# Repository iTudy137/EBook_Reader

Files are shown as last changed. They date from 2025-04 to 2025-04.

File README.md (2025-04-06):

### Copyright Dinca Tudor-Cristian 332CA 2025

# OpenBook E-Reader

1. [Block Diagram](#block-diagram)
2. [Bill of Materials](#bill-of-materials)
3. [Hardware Details](#hardware-functionality)
4. [ESP32-C6 Pins](#ESP32-C6-pin-mapping)

# Block Diagram

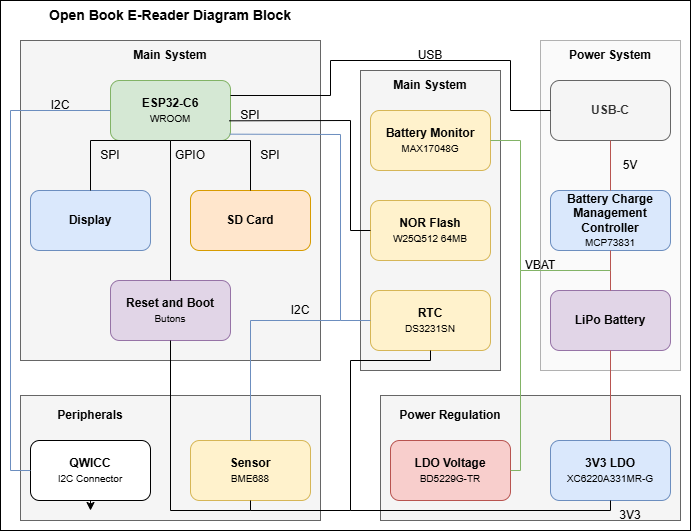
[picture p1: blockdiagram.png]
OpenBook Block Diagram


---

# Bill of Materials

| Qty | Description | Value | Parts | AVAILABILITY | CHECK_PRICES | DATASHEET |
| --- | --- | --- | --- | --- | --- | --- |
| 1 | LED | | CHG_LED | In Stock | https://ro.mouser.com/ProductDetail/ams-OSRAM/LB-Q99G.01-P1R1-35-1?qs=IPgv5n7u5QZHWhEkNg3xgA%3D%3D | https://ro.mouser.com/datasheet/2/588/prd_pim_datasheet_23471863_EN_pdf-3317093.pdf |
| 1 | SMD solder JUMPER | | SJ1 | In Stock | https://ro.mouser.com/ProductDetail/Vishay-Dale/CRCW04020000Z0EEHP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 | https://www.vishay.com/docs/20043/crcwhpe3.pdf |
| 1 | CAPACITOR, European symbol | 0.1uF/50V | EPD_C5 | In Stock | [https://ro.mouser.com/ProductDetail/Walsin/0402N151F500CT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](https://ro.mouser.com/ProductDetail/Walsin/0402N151F500CT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) | [https://ro.mouser.com/datasheet/2/210/WTC_MLCC_General_Purpose-1534899.pdf](https://ro.mouser.com/datasheet/2/210/WTC_MLCC_General_Purpose-1534899.pdf) |
| 1 | RESISTOR, European symbol | 0.47 | R3 | In Stock | https://ro.mouser.com/ProductDetail/Panasonic/ERJ-2BQJR47X?qs=18kBAoNi3c8r%252BkU3FsPM2Q%3D%3D | https://industrial.panasonic.com/cdbs/www-data/pdf/RDN0000/AOA0000C313.pdf |
| 1 | RESISTOR, European symbol | 100K | R1_PWRUSB | In Stock | [https://ro.mouser.com/ProductDetail/Welwyn-Components-TT-Electronics/WCR0402-100KFA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](https://ro.mouser.com/ProductDetail/Welwyn-Components-TT-Electronics/WCR0402-100KFA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) | https://ro.mouser.com/datasheet/2/414/TTRB_S_A0012915158_1-2565570.pdf |
| 6 | CAPACITOR, European symbol | 100nF | C1, C2, C6, C8, C10, C_DELAY | In Stock | https://ro.mouser.com/ProductDetail/KYOCERA-AVX/04023C104KAT2A-62?qs=%252BdQmOuGyFcH%2FNuvX5KIF9Q%3D%3D | https://ro.mouser.com/datasheet/2/40/X7RDielectric-2943470.pdf |
| 2 | CAPACITOR, European symbol | 100nF | C4_USB, C9 | In Stock | https://ro.mouser.com/ProductDetail/KYOCERA-AVX/04023C104KAT2A-62?qs=%252BdQmOuGyFcH%2FNuvX5KIF9Q%3D%3D | https://ro.mouser.com/datasheet/2/40/X7RDielectric-2943470.pdf |
| 1 | POLARIZED CAPACITOR, European symbol | 100uF TANT | C3 | In Stock | https://ro.mouser.com/ProductDetail/KYOCERA-AVX/TCJB106M020R0150E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 | https://ro.mouser.com/datasheet/2/40/TCJ-2887130.pdf |
| 16  | RESISTOR, European symbol | 10K | R1, R1_PINH, R1_PINH1, R2-PINH, R2-PINH1, R4, R5, R6, R7, R8, R9, R10, R_BOOT, R_CHANGE, R_CL1, R_RESET | In Stock | https://ro.mouser.com/ProductDetail/YAGEO/RC0402FR-07100KL?qs=mnq%2FyloZIXzTlUn7JAHSWg%3D%3D | https://ro.mouser.com/datasheet/2/447/YAGEO_PYu_RC_Group_51_RoHS_L_12-3313492.pdf |
| 1 | CAPACITOR, European symbol | 10uF | C7 | In Stock | https://ro.mouser.com/ProductDetail/KYOCERA-AVX/KAM05AR71E103KH?qs=Jm2GQyTW%2FbgMbf7pmhTrvw%3D%3D | https://ro.mouser.com/datasheet/2/40/AutoMLCCKAM-3216307.pdf |
| 1 | Micro SD Card Socket, Push-Push Type, Top Mount, SMT, H=1.83mm, 10u | 112A-TAAR-R03_ATTEND | J4 | In Stock | https://www.soselectronic.com/ro-ro/products/attend/112a-taar-r03-116052 | https://cdn.soselectronic.com/productdata/bd/ac/42954337/112a-taar-r03.pdf |
| 1 | RESISTOR, European symbol | 15 | R_CAPACITOR | In Stock | https://ro.mouser.com/ProductDetail/Bourns/CR0402-FX-15R0GLF?qs=sGAEpiMZZMtlubZbdhIBICGkyIRIR3aIuucn1Gj71Hk%3D | https://ro.mouser.com/datasheet/2/54/cr-1858361.pdf |
| 1 | CAPACITOR, European symbol | 1uF | C5 | In Stock | https://ro.mouser.com/ProductDetail/TAIYO-YUDEN/MAASL105CC7105MFCA01?qs=HFfMDpzxxd1Fn%2FInbJA7vw%3D%3D | https://ro.mouser.com/datasheet/2/396/TAIYO_YUDEN_04_27_2024_c_mlcc_A_e1-3451516.pdf |
| 9 | CAPACITOR, European symbol | 1uF/50V | EPD_C1, EPD_C2, EPD_C6, EPD_C7, EPD_C8, EPD_C9, EPD_C10, EPD_C11, EPD_C12 | In Stock | https://ro.mouser.com/ProductDetail/TAIYO-YUDEN/MAASU32NSB7105KTCA01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 | https://ro.mouser.com/datasheet/2/396/TDK_4_24_2024_MAASU32NSB7105KTCA01_SS-3440852.pdf |
| 1 | RESISTOR, European symbol | 2.2 | R2 | In Stock | https://ro.mouser.com/ProductDetail/YAGEO/RC0402JR-072R2L?qs=sGAEpiMZZMtlubZbdhIBIDHZZHtX2mqkbiSU5pja5tk%3D | https://ro.mouser.com/datasheet/2/447/YAGEO_PYu_RC_Group_51_RoHS_L_12-3313492.pdf |
| 1 | RESISTOR, European symbol | 200 | R1_BAT | In Stock | https://ro.mouser.com/ProductDetail/Panasonic/ERJ-U02D2000X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 | https://industrial.panasonic.com/cdbs/www-data/pdf/RDP0000/AOA0000C334.pdf |
| 2 | P-channel MOSFETs | 20V/4.2A/52mO/1.4W | Q1, Q2 | In Stock | https://ro.mouser.com/ProductDetail/Diodes-Incorporated/DMG2305UX-7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 | https://www.diodes.com/assets/Datasheets/DMG2305UX.pdf |
| 1 | RESISTOR, European symbol | 2K | R2_BAT | In Stock | https://ro.mouser.com/ProductDetail/Vishay-Dale/CRCW04022K00JNTD?qs=D1%252BtGGlbRE%252BwoJgrHBlX1g%3D%3D | https://www.vishay.com/docs/20008/dcrcw.pdf |
| 2 | CAPACITOR, European symbol | 4.7uF | C1_BAT, C2_BAT | In Stock | https://ro.mouser.com/ProductDetail/KEMET/C0402C475K8PACTU?qs=ulEaXIWI0c9ebKRT3r3htg%3D%3D | https://ro.mouser.com/datasheet/2/447/KEM_C1006_X5R_SMD-3316465.pdf |
| 3 | CAPACITOR, European symbol | 4.7uF | C1_BAT1, C1_BAT2, C5_USB | In Stock | https://ro.mouser.com/ProductDetail/KEMET/C0402C475K8PACTU?qs=ulEaXIWI0c9ebKRT3r3htg%3D%3D | https://ro.mouser.com/datasheet/2/447/KEM_C1006_X5R_SMD-3316465.pdf |
| 1 | CAPACITOR, European symbol | 4.7uF/25V | C4 | In Stock | https://ro.mouser.com/ProductDetail/KYOCERA-AVX/CM05X5R475M25AH?qs=MyNHzdoqoQJvFdZaEuclBg%3D%3D | https://ro.mouser.com/datasheet/2/40/CM_Series_e-2835982.pdf |
| 2 | RESISTOR, European symbol | 5k1 | R2-USB, R2-USB1 | In Stock | https://ro.mouser.com/ProductDetail/Vishay-Beyschlag/MCS04020C5101FE000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 | https://www.vishay.com/docs/28705/mcx0x0xpro.pdf |
| 1 | | 68uH | L1 | In Stock | https://www.digikey.de/en/products/detail/w%C3%BCrth-elektronik/744043680/1638515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 | https://www.we-online.com/components/products/datasheet/744043680.pdf |
| 1 | Voltage Detector with Adjustable Delay Time: CMOS processes are utilized to develop high precision, low current consumption CMOS reset ICs that allow arbitrary setting of the delay time. The extensive lineup includes both Nch Open Drain and CMOS output types in a wide range of detection voltages (from 2.3V to 6.0V, in 0.1V steps), enabling selection of the ideal solution based on customer requirements. In addition, the entire series is of course both lead-free and RoHS-compliant. | BD5229G-TR | IC1 | In Stock | https://ro.mouser.com/ProductDetail/ROHM-Semiconductor/BD5229G-1TR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 | https://fscdn.rohm.com/en/products/databook/datasheet/ic/power/voltage_detector/bd52xxg-1-e.pdf |
| 3 | | BUTTON_CUSYOMV1 | BOOT_BUTTON, CHANGE_BUTTON, RESET_BUTTON | Restricted Availability | https://ro.mouser.com/ProductDetail/Panasonic/EVQ-P7B01K?qs=Ow%252BOiPmaljGz0yYR%252BWV0ZQ%3D%3D | https://industry.panasonic.com/global/en/downloads/?file_cd=402906&tab=catalog&series_cd=3457 |
| 1 | Cap 0.011F 3.3V 1210 Flat Check availability | CPH3225A | C10_SUPERCAP | Not in stock | [https://www.snapeda.com/parts/CPH3225A/Seiko+Instruments/view-part/?ref=eda](https://www.snapeda.com/parts/CPH3225A/Seiko+Instruments/view-part/?ref=eda) | https://www.snapeda.com/parts/CPH3225A/Seiko%20Instruments/datasheet/ |
| 1 | Real Time Clock Serial 16-Pin SOIC W T/R     Check availability | DS3231SN# | U3 | In Stock | [https://www.snapeda.com/parts/DS3231SN%23/Analog+Devices/view-part/?ref=eda](https://www.snapeda.com/parts/DS3231SN%23/Analog+Devices/view-part/?ref=eda) | https://www.snapeda.com/parts/DS3231SN%23/Analog%20Devices/datasheet/ |
| 1 | Check availability | ESP32-C6-WROOM-1-N8 | U2 | In Stock | [https://www.snapeda.com/parts/ESP32-C6-WROOM-1-N8/Espressif+Systems/view-part/?ref=eda](https://www.snapeda.com/parts/ESP32-C6-WROOM-1-N8/Espressif+Systems/view-part/?ref=eda) | https://www.snapeda.com/parts/ESP32-C6-WROOM-1-N8/Espressif%20Systems/datasheet/ |
| 1 | VARISTOR | ESP32C6_VARISTORCN1812 | PFMF.050.1 | In Stock | https://ro.mouser.com/ProductDetail/Schurter/PFMF.050.2?qs=1auRipcfynCums5v1iucSA%3D%3D | https://ro.mouser.com/datasheet/2/358/typ_PFMF-1275918.pdf |
| 2 | Schottky Barrier Rectifier Diode | ESP32_WROVER_AVX---SD0805S020S1R0_AVX_SD0805S020S1R0_0_0AVX_SD0805S020S1R0_0_0 | D2, D7 | In Stock | https://ro.mouser.com/ProductDetail/KYOCERA-AVX/SD0805S020S1R0?qs=jCA%252BPfw4LHbpkAoSnwrdjw%3D%3D | [http://datasheets.avx.com/schottky.pdf](http://datasheets.avx.com/schottky.pdf) |
| 1 | Integrated Environmental Unit | ESP32_WROVER_BME680_BME680 | SENSOR2 | In Stock | https://ro.mouser.com/ProductDetail/Bosch-Sensortec/BME680?qs=v271MhAjFHjo0yA%2FC4OnDQ%3D%3D | [https://ro.mouser.com/datasheet/2/783/BST_BME680_DS001-1509608.pdf](https://ro.mouser.com/datasheet/2/783/BST_BME680_DS001-1509608.pdf) |
| 1 | MCP73831T Li-Ion, Li-Pol Controller | ESP32_WROVER_SPARKFUN-IC-POWER_MCP73831 | MCP73831 | In Stock | https://ro.mouser.com/ProductDetail/Microchip-Technology/MCP73831T-2DCI-OT?qs=yUQqVecv4qu38ml9qkvsJw%3D%3D | https://ro.mouser.com/datasheet/2/268/MCP73831_Family_Data_Sheet_DS20001984H-3441711.pdf |
| 1 |  (0.50mm) Surface Mount, Right Angle | FH34SRJ-24S-0.5SH_99_ | J1 | In Stock | https://ro.mouser.com/ProductDetail/Hirose-Connector/FH34SRJ-24S-0.5SH99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 | https://ro.mouser.com/datasheet/2/185/FH34SRJ_24S_0_5SH_99__CL0580_1255_6_99_2DDrawing_0-1615044.pdf |
| 1 | Check availability | MAX17048G+T10 | U4 | In Stock | [https://www.snapeda.com/parts/MAX17048G+T10/Analog+Devices/view-part/?ref=eda](https://www.snapeda.com/parts/MAX17048G+T10/Analog+Devices/view-part/?ref=eda) | https://www.snapeda.com/parts/MAX17048G+T10/Analog%20Devices/datasheet/ |
| 3 | ON SEMICONDUCTOR - MBR0530 - DIODE, SCHOTTKY, 0.5A, 30V, SOD-123 | MBR0530 | D3, D4, D5 | In Stock | [https://www.snapeda.com/parts/MBR0530/Onsemi/view-part/?ref=eda](https://www.snapeda.com/parts/MBR0530/Onsemi/view-part/?ref=eda) | https://www.snapeda.com/parts/MBR0530/ON%20Semiconductor/datasheet/ |
| 6 | Check availability | PGB1010603MR | D6, D8, D9, D10, D11, D12 | In Stock | [https://www.snapeda.com/parts/PGB1010603MR/Littelfuse/view-part/?ref=eda](https://www.snapeda.com/parts/PGB1010603MR/Littelfuse/view-part/?ref=eda) | https://www.snapeda.com/parts/PGB1010603MR/Littelfuse%20Inc./datasheet/ |
| 1 | SparkFun I2C Standard Qwiic Connector | QWIIC_RIGHT_ANGLE | J3 | In Stock | https://ro.mouser.com/ProductDetail/SparkFun/PRT-14417?qs=wd5RIQLrsJhgdz%2FpmZ%2F3GQ%3D%3D | https://ro.mouser.com/datasheet/2/813/Qwiic_Connector_Datasheet-1223982.pdf |
| 1 | CONN USB 2.0 TYPE-C R/A SMT | SAMACSYS_PARTS_USB4110-GF-A | J2 | In Stock | https://ro.mouser.com/ProductDetail/GCT/USB4110-GF-A?qs=KUoIvG%2F9IlYiZvIXQjyJeA%3D%3D | https://ro.mouser.com/datasheet/2/837/GCT_USB4110_Product_Drawing___20k_cycles-3455479.pdf |
| 1 | MOSFET N-Ch 30V 1.5A TrenchFET SC70 Vishay Si1308EDL-T1-GE3 N-channel MOSFET Transistor, 1.5 A, 30 V, 3-Pin SC-70 | SI1308EDL-T1-GE3 | Q3 | In Stock | [https://www.snapeda.com/parts/SI1308EDL-T1-GE3/Vishay+Siliconix/view-part/?ref=eda](https://www.snapeda.com/parts/SI1308EDL-T1-GE3/Vishay+Siliconix/view-part/?ref=eda) | https://www.snapeda.com/parts/SI1308EDL-T1-GE3/Vishay%20Siliconix/datasheet/ |
| 17  | Test pad | TPTP20R | TP1, TP2, TP3, TP4, TP5, TP6, TP7, TP8, TP9, TP10, TP11, TP12, TP13, TP14, TP15, TP16, TP17 | | Custom | Custom |
| 1 | Low Cap. ESD Protection Auto SOT-23-6 STMicroelectronics USBLC6-2SC6Y, Dual Uni-Directional TVS Diode Array, 6-Pin SOT-23 | USBLC6-2SC6Y | D1 | In Stock | [https://www.snapeda.com/parts/USBLC6-2SC6Y/STMicroelectronics/view-part/?ref=eda](https://www.snapeda.com/parts/USBLC6-2SC6Y/STMicroelectronics/view-part/?ref=eda) | https://www.snapeda.com/parts/USBLC6-2SC6Y/STMicroelectronics/datasheet/ |
| 1 | Check availability | W25Q512JVEIQ | U1 | In Stock | [https://www.snapeda.com/parts/W25Q512JVEIQ/Winbond+Electronics/view-part/?ref=eda](https://www.snapeda.com/parts/W25Q512JVEIQ/Winbond+Electronics/view-part/?ref=eda) | https://www.snapeda.com/parts/W25Q512JVEIQ/Winbond%20Electronics/datasheet/ |
| 1 | LDO Voltage Regulators | XC6220A331MR-G | IC4 | In Stock | https://ro.mouser.com/ProductDetail/Torex-Semiconductor/XC6220A331MR-G?qs=AsjdqWjXhJ8ZSWznL1J0gg%3D%3D | https://ro.mouser.com/datasheet/2/760/xc6220-3371556.pdf |

---

# Hardware Functionality

### Microcontroller - ESP32-C6
- **Interfaces:** SPI, I2C, GPIO, USB, PWM
- **Functions:** Wi-Fi/BLE communication, display control, sensor reading, user interface, power management
- **Operating Voltage:** 3.3V

### 1. E-Paper Display (Waveshare WSH-13187 7.5" / SPI)
- **Resolution:** 800x480
- **Interface:** SPI + GPIO  
  - **CS, DC, RST, BUSY**
- **Connected via dedicated header**

### 2. BME688 Sensor (Bosch)
- **Measures:** temperature, pressure, humidity, air quality
- **Interface:** I2C
- **Address:** configurable (default 0x76)
- **Operating Voltage:** 3.3V

### 3. RTC - DS3231SN
- **Function:** Real-Time Clock with supercapacitor backup
- **Interface:** I2C
- **Backup:** 1F Supercapacitor
- **Accuracy:** ±2ppm

### 4. Power Supply
- **Battery:** 2500mAh Li-Po
- **Charging IC:** MCP73831 (linear charger, 3.7V battery)
- **LDO Regulator:** 3.3V (AMS1117 or equivalent)
- **Connector:** USB-C (with ESD protection)

### 5. Battery Management
- **Fuel Gauge:** MAX17048
- **I2C, enables battery level monitoring**

### 6. SD Card
- **Interface:** SPI
- **Usage:** e-book storage

### 7. User Interface
- **RESET Button**
- **3 Input Buttons connected to GPIO + RC debouncing**
- **Functions:** menu navigation, page switching, simple interactions

### 8. Qwiic / Stemma QT Connector
- **Allows easy expansion with external I2C sensors**

---

## 🔋 Battery & Power Usage Summary

### 📦 Battery Capacity
- **2500mAh @ 3.7V = 9.25Wh**

---

### ⚡ Power Consumption Overview

| Mode | Current Draw | Power (W) | Battery Life |
|---|---|---|---|
| 🔘 Idle (Deep Sleep) | ~0.05 mA | ~0.0002 W | ~5.7 years |
| 😴 Light Sleep | ~1.2 mA | ~0.0044 W | ~86 days |
| 📖 Active Reading | ~77 mA | ~0.285 W  | ~32 hours |
| 🌐 Wi-Fi Active | ~177 mA | ~0.655 W  | ~14 hours |

---

# ESP32-C6 Pin Mapping

| **ESP32-C6 Pin** | **Net Label**  | **Function** | **Connected Component** | **Purpose / Description** |
|---|---|---|---|---|
| EN | RESET | Enable | ESP32-C6 | Main reset input to the microcontroller |
| IO0 | INT_RTC | GPIO (Interrupt) | RTC DS3231SN | Receives interrupt signal from RTC (e.g. alarm trigger) |
| IO1 | 32KHZ | GPIO (Clock In) | RTC DS3231SN | 32kHz clock output from RTC |
| IO2 | MISO | SPI MISO | SD Card | Receives data from SD card |
| IO3 | EPD_BUSY | GPIO (Input) | E-Paper Display | Indicates when the E-Paper display is busy |
| IO4 | SS_SD | SPI CS | SD Card | Chip select for SD card |
| IO5 | EPD_CS | SPI CS | E-Paper Display | Chip select for E-Paper display |
| IO6 | SCK | SPI Clock | E-Paper Display, SD Card | Clock signal for shared SPI bus |
| IO7 | MOSI | SPI MOSI | E-Paper Display, SD Card | Sends data to display and SD card |
| IO8 | GPIO9 | GPIO | General Purpose | Spare GPIO or future expansion |
| IO9 | IO/BOOT | GPIO / Boot | Boot Button | Used for flashing the ESP32 (held LOW on boot to enter flash mode) |
| IO10 | EPD_CS | SPI CS | E-Paper Display | Redundant label for CS (appears twice in schematic) |
| IO11 | FLASH_CS | SPI CS | External NOR Flash | Chip select for SPI flash |
| IO12 | USB_D- | USB D- | USB-C Connector | Native USB communication |
| IO13 | USB_D+ | USB D+ | USB-C Connector | Native USB communication |
| IO15 | IO/CHANGE | GPIO | General Purpose / Input | Connected to a user-defined I/O (possibly an interrupt line or button) |
| IO16 | TX | UART TX | Serial Communication | Transmit line for UART debugging |
| IO17 | RX | UART RX | Serial Communication | Receive line for UART debugging |
| IO18 | RTC_RST | GPIO | RTC DS3231SN | Allows resetting the RTC externally |
| IO19 | I2C_PW | GPIO (Power Ctrl)  | I2C Peripherals | Enables power to I2C devices (BME688, MAX17048, etc.) |
| IO20 | EPD_3V3_C | GPIO (Power Ctrl)  | E-Paper Display | Powers the EPD circuit via transistor / switch |
| IO21 | SDA | I2C Data | BME688, RTC, MAX17048 | Shared data line for I2C peripherals |
| IO22 | SCL | I2C Clock | BME688, RTC, MAX17048 | Shared clock line for I2C peripherals |
| IO23 | EPD_RSR | GPIO | E-Paper Display | Reset line for E-Paper display |
| 3V3 | 3V3 | Power | All Components | Main power rail (3.3V) |
| GND | GND | Ground | All Components | Ground reference for the entire system |

---

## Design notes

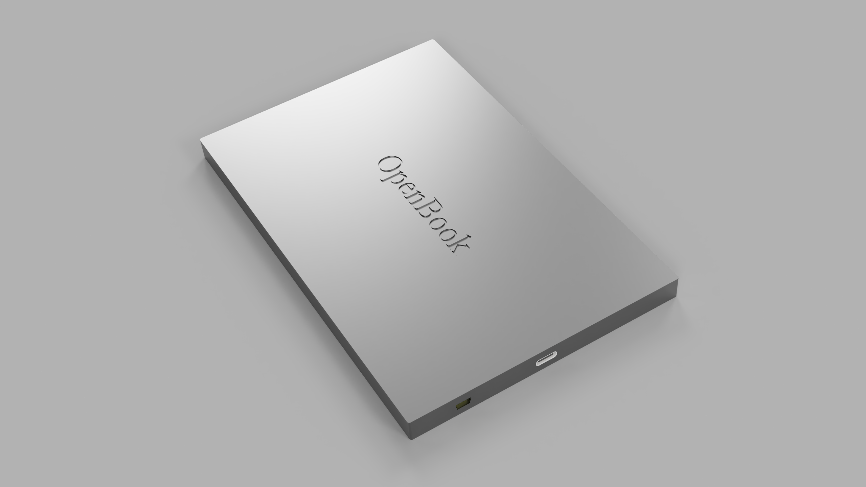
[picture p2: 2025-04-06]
Images/BackView.png

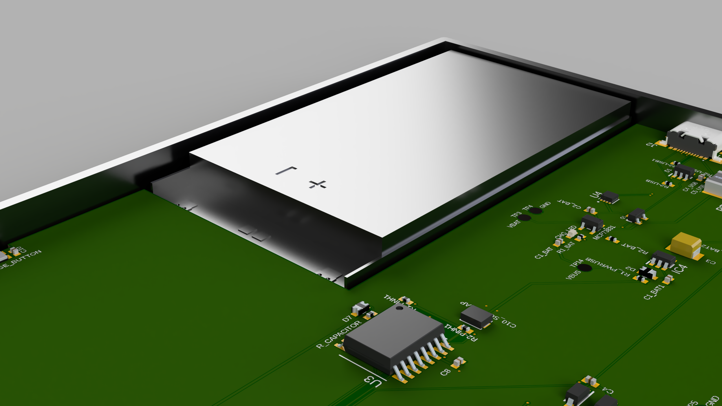
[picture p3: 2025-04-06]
Images/Battery.png

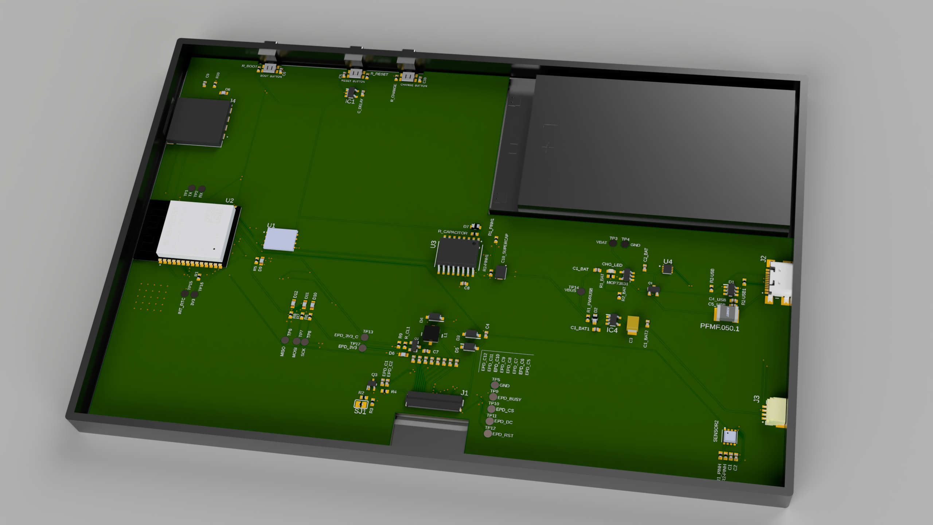
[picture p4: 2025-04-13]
Images/Board.png

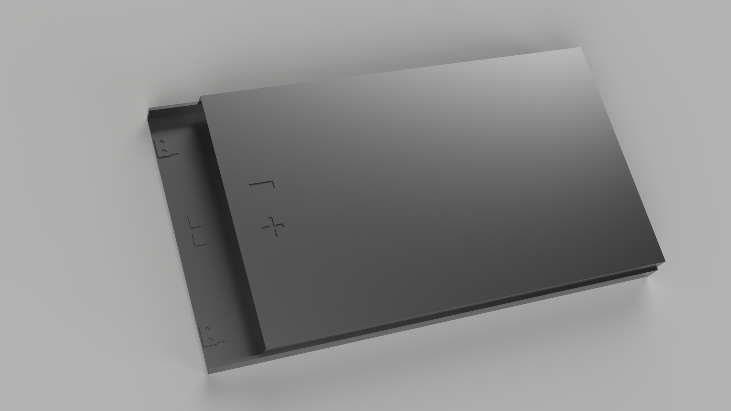
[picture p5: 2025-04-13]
Images/Battery_Profile.png

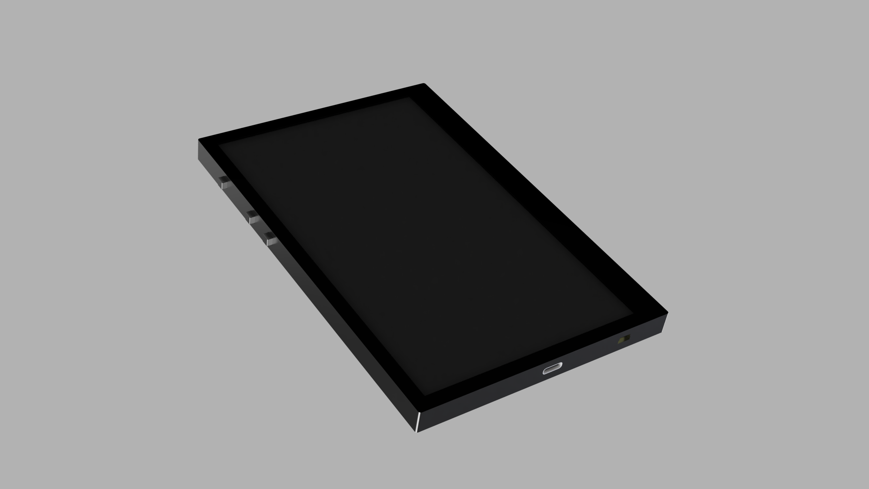
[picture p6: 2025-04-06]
Images/FrontView.png

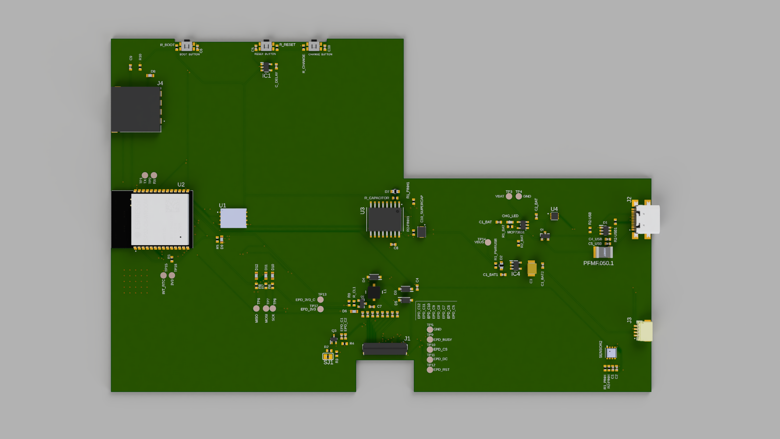
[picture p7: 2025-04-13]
Images/PCB.png

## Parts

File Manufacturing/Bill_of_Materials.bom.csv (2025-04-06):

Qty | Value | Device | Package | Parts | Description | ARROW_PART_NUMBER | ARROW_PRICE-STOCK | AVAILABILITY | CENTROID_NOT_SPECIFIED | CHECK_PRICES | COPYRIGHT | DATASHEET | DESCRIPTION | DIGIKEY_DESCRIPTION | DIGIKEY_PART_NUMBER | HEIGHT | LEAD_FREE | MANUFACTURER_NAME | MANUFACTURER_PART_NUMBER | MF | MFR_NAME | MOUSER_PART_NUMBER | MOUSER_PRICE-STOCK | MOUSER_TESTING_PART_NUMBER | MOUSER_TESTING_PRICE-STOCK | MP | MPN | PACKAGE | POPULARITY | PREFIX | PRICE | PROD_ID | PURCHASE-URL | ROHS | SNAPEDA_LINK | SPICEMODEL | SPICEPREFIX | TEMPERATURE_RANGE_HIGH | TEMPERATURE_RANGE_LOW | TP_SIGNAL_NAME | VALUE
1 |  | ADAFRUIT_LEDCHIP-LED0603 | ADAFRUIT_CHIP-LED0603 | CHG_LED | LED
1 |  | SJ | SJ | SJ1 | SMD solder JUMPER |  |  |  |  |  |  |  |  |  |  |  |  |  |  |  |  |  |  |  |  |  |  |  | 3
1 | 0.1uF/50V | EAGLE-LTSPICE_CC0402 | EAGLE-LTSPICE_C0402 | EPD_C5 | CAPACITOR, European symbol |  |  |  |  |  |  |  |  |  |  |  |  |  |  |  |  |  |  |  |  |  |  |  |  |  |  |  |  |  |  | NONE | C
1 | 0.47 | ESP32_WROVER_EAGLE-LTSPICE_RR0402 | ESP32_WROVER_EAGLE-LTSPICE_R0402 | R3 | RESISTOR, European symbol |  |  |  |  |  |  |  |  |  |  |  |  |  |  |  |  |  |  |  |  |  |  |  |  |  |  |  |  |  |  | NONE | R
1 | 100K | ESP32_WROVER_EAGLE-LTSPICE_RR0402 | ESP32_WROVER_EAGLE-LTSPICE_R0402 | R1_PWRUSB | RESISTOR, European symbol |  |  |  |  |  |  |  |  |  |  |  |  |  |  |  |  |  |  |  |  |  |  |  |  |  |  |  |  |  |  | NONE | R
6 | 100nF | EAGLE-LTSPICE_CC0402 | EAGLE-LTSPICE_C0402 | C1, C2, C6, C8, C10, C_DELAY | CAPACITOR, European symbol |  |  |  |  |  |  |  |  |  |  |  |  |  |  |  |  |  |  |  |  |  |  |  |  |  |  |  |  |  |  | NONE | C
2 | 100nF | ESP32_WROVER_EAGLE-LTSPICE_CC0402 | EAGLE-LTSPICE_C0402 | C4_USB, C9 | CAPACITOR, European symbol |  |  |  |  |  |  |  |  |  |  |  |  |  |  |  |  |  |  |  |  |  |  |  |  |  |  |  |  |  |  | NONE | C
1 | 100uF TANT | RCL_CPOL-EUCT3528 | RCL_CT3528 | C3 | POLARIZED CAPACITOR, European symbol |  |  |  |  |  |  |  |  |  |  |  |  |  |  |  |  |  |  |  |  |  |  |  | 0 |  |  |  |  |  |  |  | C
16 | 10K | ESP32_WROVER_EAGLE-LTSPICE_RR0402 | ESP32_WROVER_EAGLE-LTSPICE_R0402 | R1, R1_PINH, R1_PINH1, R2-PINH, R2-PINH1, R4, R5, R6, R7, R8, R9, R10, R_BOOT, R_CHANGE, R_CL1, R_RESET | RESISTOR, European symbol |  |  |  |  |  |  |  |  |  |  |  |  |  |  |  |  |  |  |  |  |  |  |  |  |  |  |  |  |  |  | NONE | R
1 | 10uF | EAGLE-LTSPICE_CC0402 | EAGLE-LTSPICE_C0402 | C7 | CAPACITOR, European symbol |  |  |  |  |  |  |  |  |  |  |  |  |  |  |  |  |  |  |  |  |  |  |  |  |  |  |  |  |  |  | NONE | C
1 | 112A-TAAR-R03_ATTEND | 112A-TAAR-R03_ATTEND | 112ATAARR03ATTEND | J4 | Micro SD Card Socket, Push-Push Type, Top Mount, SMT, H=1.83mm, 10u |  |  |  |  |  |  |  | Micro SD Card Socket | Push-Push Type | Top Mount | SMT | H=1.83mm | 10u |  |  | 1.9mm |  | ATTEND | 112A-TAAR-R03 ATTEND
1 | 15 | ESP32_WROVER_EAGLE-LTSPICE_RR0402 | ESP32_WROVER_EAGLE-LTSPICE_R0402 | R_CAPACITOR | RESISTOR, European symbol |  |  |  |  |  |  |  |  |  |  |  |  |  |  |  |  |  |  |  |  |  |  |  |  |  |  |  |  |  |  | NONE | R
1 | 1uF | EAGLE-LTSPICE_CC0402 | EAGLE-LTSPICE_C0402 | C5 | CAPACITOR, European symbol |  |  |  |  |  |  |  |  |  |  |  |  |  |  |  |  |  |  |  |  |  |  |  |  |  |  |  |  |  |  | NONE | C
9 | 1uF/50V | EAGLE-LTSPICE_CC0402 | EAGLE-LTSPICE_C0402 | EPD_C1, EPD_C2, EPD_C6, EPD_C7, EPD_C8, EPD_C9, EPD_C10, EPD_C11, EPD_C12 | CAPACITOR, European symbol |  |  |  |  |  |  |  |  |  |  |  |  |  |  |  |  |  |  |  |  |  |  |  |  |  |  |  |  |  |  | NONE | C
1 | 2.2 | ESP32_WROVER_EAGLE-LTSPICE_RR0402 | ESP32_WROVER_EAGLE-LTSPICE_R0402 | R2 | RESISTOR, European symbol |  |  |  |  |  |  |  |  |  |  |  |  |  |  |  |  |  |  |  |  |  |  |  |  |  |  |  |  |  |  | NONE | R
1 | 200 | ESP32_WROVER_EAGLE-LTSPICE_RR0402 | ESP32_WROVER_EAGLE-LTSPICE_R0402 | R1_BAT | RESISTOR, European symbol |  |  |  |  |  |  |  |  |  |  |  |  |  |  |  |  |  |  |  |  |  |  |  |  |  |  |  |  |  |  | NONE | R
2 | 20V/4.2A/52mO/1.4W | ESP32_WROVER_SPARKFUN-DISCRETESEMI_MOSFET_PCH-DMG2305UX-7 | ESP32_WROVER_SPARKFUN-DISCRETESEMI_SOT23-3 | Q1, Q2 | P-channel MOSFETs |  |  |  |  |  |  |  |  |  |  |  |  |  |  |  |  |  |  |  |  |  |  |  |  |  |  | TRAN-14388 |  |  |  |  |  |  |  |  | 20V/4.2A/52mO/1.4W
1 | 2K | ESP32_WROVER_EAGLE-LTSPICE_RR0402 | ESP32_WROVER_EAGLE-LTSPICE_R0402 | R2_BAT | RESISTOR, European symbol |  |  |  |  |  |  |  |  |  |  |  |  |  |  |  |  |  |  |  |  |  |  |  |  |  |  |  |  |  |  | NONE | R
2 | 4.7uF | EAGLE-LTSPICE_CC0402 | EAGLE-LTSPICE_C0402 | C1_BAT, C2_BAT | CAPACITOR, European symbol |  |  |  |  |  |  |  |  |  |  |  |  |  |  |  |  |  |  |  |  |  |  |  |  |  |  |  |  |  |  | NONE | C
3 | 4.7uF | ESP32_WROVER_EAGLE-LTSPICE_CC0402 | EAGLE-LTSPICE_C0402 | C1_BAT1, C1_BAT2, C5_USB | CAPACITOR, European symbol |  |  |  |  |  |  |  |  |  |  |  |  |  |  |  |  |  |  |  |  |  |  |  |  |  |  |  |  |  |  | NONE | C
1 | 4.7uF/25V | EAGLE-LTSPICE_CC0402 | EAGLE-LTSPICE_C0402 | C4 | CAPACITOR, European symbol |  |  |  |  |  |  |  |  |  |  |  |  |  |  |  |  |  |  |  |  |  |  |  |  |  |  |  |  |  |  | NONE | C
2 | 5k1 | ESP32_WROVER_EAGLE-LTSPICE_RR0402 | ESP32_WROVER_EAGLE-LTSPICE_R0402 | R2-USB, R2-USB1 | RESISTOR, European symbol |  |  |  |  |  |  |  |  |  |  |  |  |  |  |  |  |  |  |  |  |  |  |  |  |  |  |  |  |  |  | NONE | R
1 | 68uH | 744043680IND_4828-WE-TPC_WRE | IND_4828-WE-TPC_WRE | L1 |  |  |  |  |  |  | Copyright (C) 2024 Ultra Librarian. All rights reserved. |  |  |  |  |  |  |  | 744043680 |  | Wurth Electronics
1 | BD5229G-TR | BD5229G-TR | SOT95P280X125-5N | IC1 | Voltage Detector with Adjustable Delay Time: CMOS processes are utilized to develop high precision, low current consumption CMOS reset ICs that allow arbitrary setting of the delay time. The extensive lineup includes both Nch Open Drain and CMOS output types in a wide range of detection voltages (from 2.3V to 6.0V, in 0.1V steps), enabling selection of the ideal solution based on customer requirements. In addition, the entire series is of course both lead-free and RoHS-compliant. |  |  |  |  |  |  |  | Voltage Detector with Adjustable Delay Time: CMOS processes are utilized to develop high precision | low current consumption CMOS reset ICs that allow arbitrary setting of the delay time. The extensive lineup includes both Nch Open Drain and CMOS output types in a wide range of detection voltages (from 2.3V to 6.0V | in 0.1V steps) | enabling selection of the ideal solution based on customer requirements. In addition | the entire series is of course both lead-free and RoHS-compliant. |  |  | 1.25mm |  | ROHM Semiconductor | BD5229G-TR |  |  | 755-BD5229G-TR | https://www.mouser.co.uk/ProductDetail/ROHM-Semiconductor/BD5229G-TR?qs=4kLU8WoGk0vvnhrrYwdszw%3D%3D
3 | BUTTON_CUSYOMV1 | BUTTON_CUSYOMV1 | MYBUTTON | BOOT_BUTTON, CHANGE_BUTTON, RESET_BUTTON
1 | CPH3225A | CPH3225A | CAPCP3225X100N | C10_SUPERCAP | Cap 0.011F 3.3V 1210 Flat Check availability |  |  | Not in stock |  | https://www.snapeda.com/parts/CPH3225A/Seiko+Instruments/view-part/?ref=eda |  |  | 11 mF (EDLC) Supercapacitor 3.3 V 1210 (3225 Metric) - - |  |  |  |  |  |  | Seiko Instruments |  |  |  |  |  | CPH3225A |  | 1210 Seiko |  |  | None |  | https://www.snapeda.com/api/url_track_click_mouser/?unipart_id=562593&manufacturer=Seiko Instruments&part_name=CPH3225A&search_term=None |  | https://www.snapeda.com/parts/CPH3225A/Seiko+Instruments/view-part/?ref=snap
1 | DS3231SN# | DS3231SN# | SOIC127P1032X265-16N | U3 | Real Time Clock Serial 16-Pin SOIC W T/R Check availability |  |  | In Stock |  | https://www.snapeda.com/parts/DS3231SN%23/Analog+Devices/view-part/?ref=eda |  |  | Extremely Accurate I²C-Integrated RTC/TCXO/Crystal |  |  |  |  |  |  | Analog Devices |  |  |  |  |  | DS3231SN# |  | SOIC-16 Maxim |  |  | None |  | https://www.snapeda.com/api/url_track_click_mouser/?unipart_id=99048&manufacturer=Analog Devices&part_name=DS3231SN#&search_term=None |  | https://www.snapeda.com/parts/DS3231SN%23/Analog+Devices/view-part/?ref=snap
1 | ESP32-C6-WROOM-1-N8 | ESP32-C6-WROOM-1-N8 | XCVR_ESP32-C6-WROOM-1-N8 | U2 | Check availability |  |  | In Stock |  | https://www.snapeda.com/parts/ESP32-C6-WROOM-1-N8/Espressif+Systems/view-part/?ref=eda |  |  | Multiprotocol Modules ESP32-C6 module | Wi-Fi 6 in 2.4 GHz band | Bluetooth 5 | Zigbee 3.0 and Thread. ESP34-WROOM Compatible - ENGINEERING SAMPLE |  |  |  |  |  |  | Espressif Systems |  |  |  |  |  | ESP32-C6-WROOM-1-N8 |  | None |  |  | None |  |  |  | https://www.snapeda.com/parts/ESP32-C6-WROOM-1-N8/Espressif+Systems/view-part/?ref=snap
1 | ESP32C6_VARISTORCN1812 | ESP32C6_VARISTORCN1812 | ESP32C6_VARISTOR_CT/CN1812 | PFMF.050.1 | VARISTOR |  |  |  |  |  |  |  |  |  |  |  |  |  |  |  |  |  |  |  |  |  |  |  | 0
2 | ESP32_WROVER_AVX---SD0805S020S1R0_AVX_SD0805S020S1R0_0_0AVX_SD0805S020S1R0_0_0 | ESP32_WROVER_AVX---SD0805S020S1R0_AVX_SD0805S020S1R0_0_0AVX_SD0805S020S1R0_0_0 | ESP32_WROVER_AVX---SD0805S020S1R0_AVX_SD0805S020S1R0_0 | D2, D7 | Schottky Barrier Rectifier Diode |  |  |  | No |  |  | http://datasheets.avx.com/schottky.pdf |  | DIODE SCHOTTKY 20V 1A 0805 | 478-7800-1-ND |  | yes |  |  | AVX |  | 581-SD0805S020S1R0 |  |  |  |  |  | 0805 (2012 metric) |  | D |  |  |  | yes |  |  |  | +125°C | -55°C
1 | ESP32_WROVER_BME680_BME680 | ESP32_WROVER_BME680_BME680 | ESP32_WROVER_BME680_PSON80P300X300X100-8N | SENSOR2 | Integrated Environmental Unit |  |  | Unavailable |  |  |  |  | Integrated Environmental Unit |  |  |  |  |  |  | Bosch Sensortec |  |  |  |  |  | BME680 |  | LGA-8 Bosch Tools |  |  | None
1 | ESP32_WROVER_SPARKFUN-IC-POWER_MCP73831 | ESP32_WROVER_SPARKFUN-IC-POWER_MCP73831 | ESP32_WROVER_SPARKFUN-IC-POWER_SOT23-5 | MCP73831 | MCP73831T Li-Ion, Li-Pol Controller |  |  |  |  |  |  |  |  |  |  |  |  |  |  |  |  |  |  |  |  |  |  |  |  |  |  | IC-09995
1 | FH34SRJ-24S-0.5SH_99_ | FH34SRJ-24S-0.5SH_99_ | FH34SRJ24S05SH99 | J1 | (0.50mm) Surface Mount, Right Angle |  |  |  |  |  |  |  | 24 Position FFC | FPC Connector Contacts | (0.50mm) Surface Mount | Right Angle |  |  | 1.1mm |  | Hirose | FH34SRJ-24S-0.5SH(99) |  |  | 798-FH34SRJ24S05SH99 | https://www.mouser.co.uk/ProductDetail/Hirose-Connector/FH34SRJ-24S-0.5SH99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
1 | MAX17048G+T10 | MAX17048G+T10 | SON50P200X200X80-9N | U4 | Check availability |  |  | In Stock |  | https://www.snapeda.com/parts/MAX17048G+T10/Analog+Devices/view-part/?ref=eda |  |  | 3µA 1-Cell/2-Cell Fuel Gauge with ModelGauge |  |  |  |  |  |  | Analog Devices |  |  |  |  |  | MAX17048G+T10 |  | TDFN-8 Maxim |  |  | None |  | https://www.snapeda.com/api/url_track_click_mouser/?unipart_id=329239&manufacturer=Analog Devices&part_name=MAX17048G+T10&search_term=None |  | https://www.snapeda.com/parts/MAX17048G+T10/Analog+Devices/view-part/?ref=snap
3 | MBR0530 | MBR0530 | SOD3716X135N | D3, D4, D5 | ON SEMICONDUCTOR - MBR0530 - DIODE, SCHOTTKY, 0.5A, 30V, SOD-123 |  |  | In Stock |  | https://www.snapeda.com/parts/MBR0530/Onsemi/view-part/?ref=eda |  |  | Diode Schottky 30 V 500mA Surface Mount SOD-123 |  |  |  |  |  |  | ON Semiconductor |  |  |  |  |  | MBR0530 |  | SOD-123-2 ON Semiconductor |  |  | None |  | https://www.snapeda.com/api/url_track_click_mouser/?unipart_id=179458&manufacturer=ON Semiconductor&part_name=MBR0530&search_term=None |  | https://www.snapeda.com/parts/MBR0530/Onsemi/view-part/?ref=snap
6 | PGB1010603MR | PGB1010603MR | DIOC1608X36N | D6, D8, D9, D10, D11, D12 | Check availability |  |  | In Stock |  | https://www.snapeda.com/parts/PGB1010603MR/Littelfuse/view-part/?ref=eda |  |  | 150V (Typ) Clamp - Ipp Tvs Diode Surface Mount 0603 (1608 Metric) |  |  |  |  |  |  | Littelfuse Inc. |  |  |  |  |  | PGB1010603MR |  | 0603 Littelfuse Inc. |  |  | None |  | https://www.snapeda.com/api/url_track_click_mouser/?unipart_id=5659453&manufacturer=Littelfuse Inc.&part_name=PGB1010603MR&search_term=None |  | https://www.snapeda.com/parts/PGB1010603MR/Littelfuse/view-part/?ref=snap
1 | QWIIC_RIGHT_ANGLE | QWIIC_CONNECTORJS-1MM | JST04_1MM_RA | J3 | SparkFun I2C Standard Qwiic Connector |  |  |  |  |  |  |  |  |  |  |  |  |  |  |  |  |  |  |  |  |  |  |  |  |  |  | CONN-13694 |  |  |  |  |  |  |  |  | QWIIC_RIGHT_ANGLE
1 | SAMACSYS_PARTS_USB4110-GF-A | SAMACSYS_PARTS_USB4110-GF-A | SAMACSYS_PARTS_USB4110GFA | J2 | CONN USB 2.0 TYPE-C R/A SMT |  |  |  |  |  |  |  | CONN USB 2.0 TYPE-C R/A SMT |  |  | 3.26mm |  | GCT (GLOBAL CONNECTOR TECHNOLOGY) | USB4110-GF-A |  |  | 640-USB4110-GF-A | https://www.mouser.co.uk/ProductDetail/GCT/USB4110-GF-A?qs=KUoIvG%2F9IlYiZvIXQjyJeA%3D%3D
1 | SI1308EDL-T1-GE3 | SI1308EDL-T1-GE3 | SOT65P210X110-3N | Q3 | MOSFET N-Ch 30V 1.5A TrenchFET SC70 Vishay Si1308EDL-T1-GE3 N-channel MOSFET Transistor, 1.5 A, 30 V, 3-Pin SC-70 |  |  | In Stock |  | https://www.snapeda.com/parts/SI1308EDL-T1-GE3/Vishay+Siliconix/view-part/?ref=eda |  |  | Si1308EDL-T1-GE3 N-channel MOSFET Transistor | 1.5 A | 30 V | 3-Pin SC-70 | Siliconix / Vishay SI1308EDL-T1-GE3 |  |  |  |  |  |  | Vishay Siliconix |  |  |  |  |  | SI1308EDL-T1-GE3 |  | SOT-323 Vishay Semiconductor |  |  | None |  | https://www.snapeda.com/api/url_track_click_mouser/?unipart_id=274603&manufacturer=Vishay Siliconix&part_name=SI1308EDL-T1-GE3&search_term=None |  | https://www.snapeda.com/parts/SI1308EDL-T1-GE3/Vishay+Siliconix/view-part/?ref=snap
17 | TPTP20R | TPTP20R | TP20R | TP1, TP2, TP3, TP4, TP5, TP6, TP7, TP8, TP9, TP10, TP11, TP12, TP13, TP14, TP15, TP16, TP17 | Test pad |  |  |  |  |  |  |  |  |  |  |  |  |  |  |  |  |  |  |  |  |  |  |  | 2
1 | USBLC6-2SC6Y | USBLC6-2SC6Y | SOT95P280X145-6N | D1 | Low Cap. ESD Protection Auto SOT-23-6 STMicroelectronics USBLC6-2SC6Y, Dual Uni-Directional TVS Diode Array, 6-Pin SOT-23 |  |  | In Stock |  | https://www.snapeda.com/parts/USBLC6-2SC6Y/STMicroelectronics/view-part/?ref=eda |  |  | 17V Clamp 5A (8/20µs) Ipp Tvs Diode Surface Mount SOT-23-6 |  |  |  |  |  |  | STMicroelectronics |  |  |  |  |  | USBLC6-2SC6Y |  | SOT-23-6 STMicroelectronics |  |  | None |  |  |  | https://www.snapeda.com/parts/USBLC6-2SC6Y/STMicroelectronics/view-part/?ref=snap
1 | W25Q512JVEIQ | W25Q512JVEIQ | SON127P600X800X80-9N | U1 | Check availability |  |  | In Stock |  | https://www.snapeda.com/parts/W25Q512JVEIQ/Winbond+Electronics/view-part/?ref=eda |  |  | FLASH - NOR Memory IC 512Mb (64M x 8) SPI - Quad I/O 133 MHz 8-WSON (8x6) |  |  |  |  |  |  | Winbond Electronics |  |  |  |  |  | W25Q512JVEIQ |  | Package |  |  | None |  |  |  | https://www.snapeda.com/parts/W25Q512JVEIQ/Winbond+Electronics/view-part/?ref=snap
1 | XC6220A331MR-G | XC6220A331MR-G | SOT95P280X120-5N | IC4 | LDO Voltage Regulators |  |  |  |  |  |  |  | LDO Voltage Regulators |  |  | 1.2mm |  | Torex | XC6220A331MR-G |  |  | 865-XC6220A331MR-G | https://www.mouser.co.uk/ProductDetail/Torex-Semiconductor/XC6220A331MR-G?qs=AsjdqWjXhJ8ZSWznL1J0gg%3D%3D

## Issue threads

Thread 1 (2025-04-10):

90 degree routing

Vladmun1337, 2025-04-10:
In the PCB design you have a few routes that form 90 degree angles, usually on the top layer.

From what was observed, this issue seems to generally appear on 3V3 power lines. Please fix them.

Some examples:

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

iTudy137, 2025-04-13:
Thanks for bringing it to my attention. I've removed the 90 degree angles.

Closed 2025-04-13.

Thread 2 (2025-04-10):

Component labels in silkscreen overlap routing

Vladmun1337, 2025-04-10:
For a couple of the components on the PCB design, their corresponding labels overlap with the routing. Some labels are placed over two layers of routing and can be hard to read. The R_CHARGE resistance's label overlaps a via point near the CHANGE_BUTTON. Please fix this.

Silkscreen over routes:

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

Silkscreen over via:

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

iTudy137, 2025-04-13:
Thank you for the suggestion to not have labels labels intersecting with the routing. I analyzed my entire board and repositioned the labels to fix the issue.

Closed 2025-04-13.

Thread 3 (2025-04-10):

No PCB measurements in layout

Vladmun1337, 2025-04-10:
The board's dimensions are not written in the PCB layout design. This makes it hard to check if holes and component placements are right.

Please add dimensions in mm for all sides of the PCB and for the distances of the components that exit the board (ex: buttons, SD card reader).

iTudy137, 2025-04-13:
Thank you for the suggestion. Now my project has all the important measurements in the documentation layer of the PCB.

Closed 2025-04-13.

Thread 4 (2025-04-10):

Fix board width

Vladmun1337, 2025-04-10:
The width of your board doesn't seem to correspond to the given specifications. Please update to 1mm.

iTudy137, 2025-04-13:
Thanks you. I modified the board's width to the recommended 1mm.

Closed 2025-04-13.

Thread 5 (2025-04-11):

Gaps in ground plane

Vladmun1337, 2025-04-11:
In the PCB design, it seems that the ground plane has inconsistencies. There are regions in which no connection is made. Please fix this.

Examples:

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

iTudy137, 2025-04-13:
Hello, i understood my board was having an incomplete ground plane and i did my best to fix it. Thanks for the recommendation!

Closed 2025-04-13.

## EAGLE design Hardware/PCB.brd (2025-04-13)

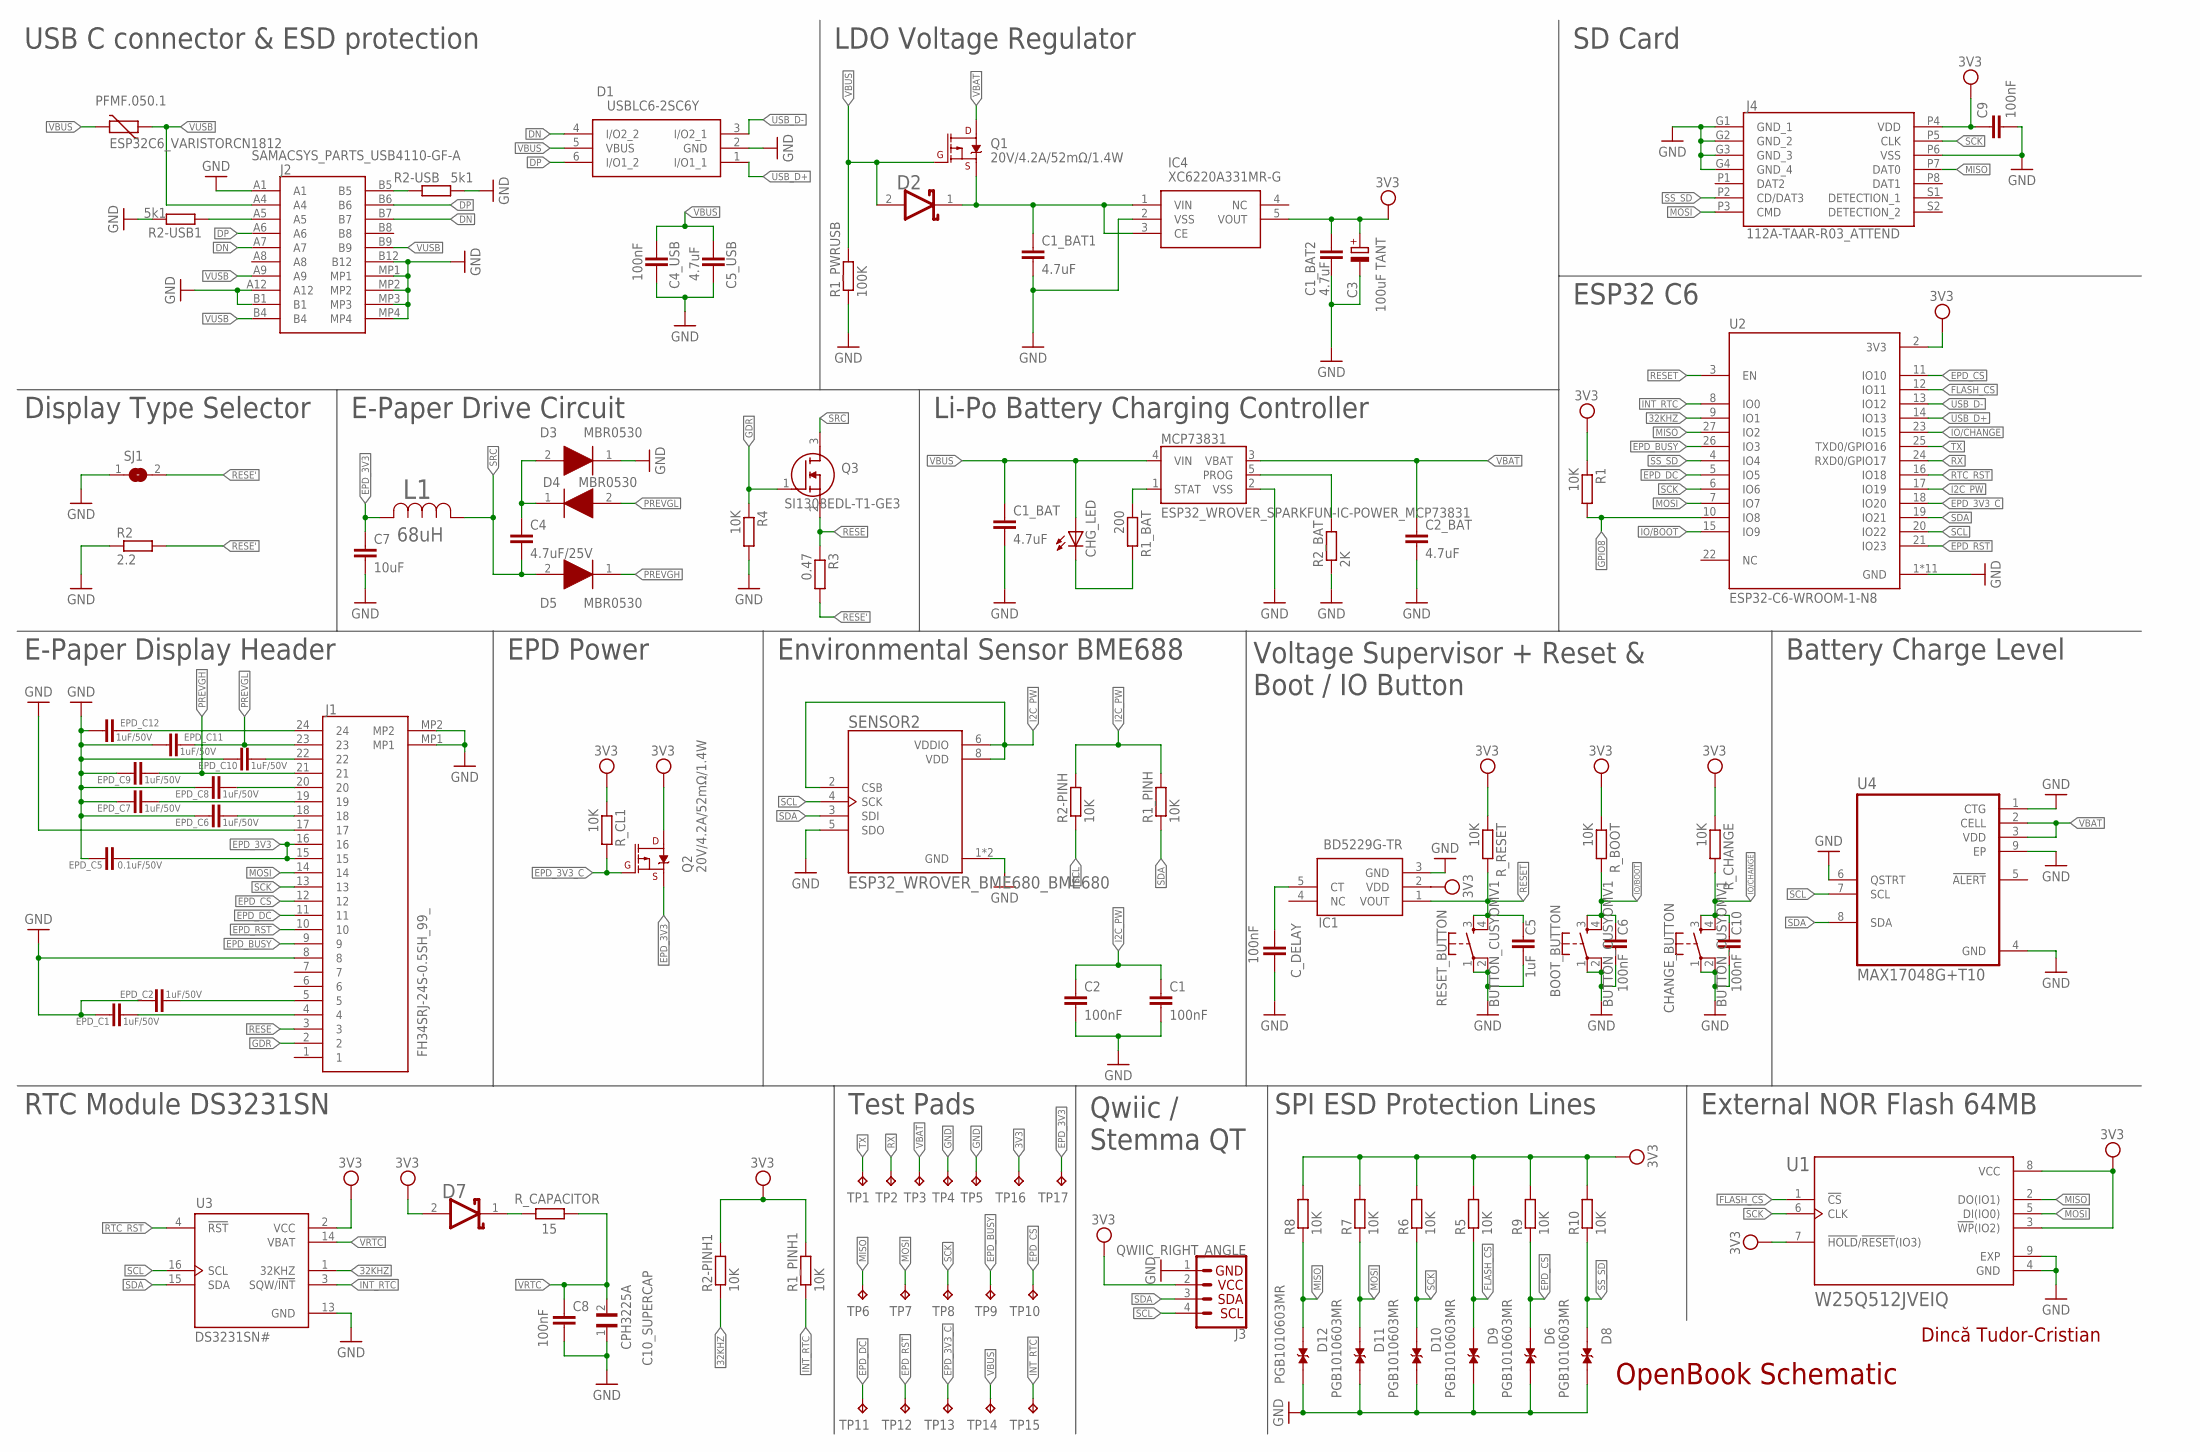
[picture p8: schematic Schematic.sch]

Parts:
BOOT_BUTTON: BUTTON_CUSYOMV1; MYBUTTON
C1, C2, C4_USB, C6, C8, C9, C10: 100nF; EAGLE-LTSPICE_C0402
C1_BAT, C1_BAT1, C1_BAT2, C2_BAT, C5_USB: 4.7uF; EAGLE-LTSPICE_C0402
C3: 100uF TANT; RCL_CT3528
C4: 4.7uF/25V; EAGLE-LTSPICE_C0402
C5: 1uF; EAGLE-LTSPICE_C0402
C7: 10uF; EAGLE-LTSPICE_C0402
C10_SUPERCAP: CPH3225A; CAPCP3225X100N
CHANGE_BUTTON: BUTTON_CUSYOMV1; MYBUTTON
CHG_LED: ADAFRUIT_LEDCHIP-LED0603; ADAFRUIT_CHIP-LED0603
C_DELAY: 100nF; EAGLE-LTSPICE_C0402
D1: USBLC6-2SC6Y; SOT95P280X145-6N
D2, D7: ESP32_WROVER_AVX---SD0805S020S1R0_AVX_SD0805S020S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; ESP32_WROVER_AVX---SD0805S020S1R0_AVX_SD0805S020S1R0_0
D3, D4, D5: MBR0530; SOD3716X135N
D6, D8, D9, D10, D11, D12: PGB1010603MR; DIOC1608X36N
EPD_C1, EPD_C2, EPD_C6, EPD_C7, EPD_C8, EPD_C9, EPD_C10, EPD_C11, EPD_C12: 1uF/50V; EAGLE-LTSPICE_C0402
EPD_C5: 0.1uF/50V; EAGLE-LTSPICE_C0402
IC1: BD5229G-TR; SOT95P280X125-5N
IC4: XC6220A331MR-G; SOT95P280X120-5N
J1: FH34SRJ-24S-0.5SH_99_; FH34SRJ24S05SH99
J2: SAMACSYS_PARTS_USB4110-GF-A; SAMACSYS_PARTS_USB4110GFA
J3: QWIIC_RIGHT_ANGLE; JST04_1MM_RA
J4: 112A-TAAR-R03_ATTEND; 112ATAARR03ATTEND
L1: 68uH; IND_4828-WE-TPC_WRE
MCP73831: ESP32_WROVER_SPARKFUN-IC-POWER_MCP73831; ESP32_WROVER_SPARKFUN-IC-POWER_SOT23-5
PFMF.050.1: ESP32C6_VARISTORCN1812; ESP32C6_VARISTOR_CT/CN1812
Q1, Q2: 20V/4.2A/52mΩ/1.4W; ESP32_WROVER_SPARKFUN-DISCRETESEMI_SOT23-3
Q3: SI1308EDL-T1-GE3; SOT65P210X110-3N
R1, R1_PINH, R1_PINH1, R2-PINH, R2-PINH1, R4, R5, R6, R7, R8, R9, R10: 10K; ESP32_WROVER_EAGLE-LTSPICE_R0402
R1_BAT: 200; ESP32_WROVER_EAGLE-LTSPICE_R0402
R1_PWRUSB: 100K; ESP32_WROVER_EAGLE-LTSPICE_R0402
R2: 2.2; ESP32_WROVER_EAGLE-LTSPICE_R0402
R2-USB, R2-USB1: 5k1; ESP32_WROVER_EAGLE-LTSPICE_R0402
R2_BAT: 2K; ESP32_WROVER_EAGLE-LTSPICE_R0402
R3: 0.47; ESP32_WROVER_EAGLE-LTSPICE_R0402
RESET_BUTTON: BUTTON_CUSYOMV1; MYBUTTON
R_BOOT: 10K; ESP32_WROVER_EAGLE-LTSPICE_R0402
R_CAPACITOR: 15; ESP32_WROVER_EAGLE-LTSPICE_R0402
R_CHANGE: 10K; ESP32_WROVER_EAGLE-LTSPICE_R0402
R_CL1: 10K; ESP32_WROVER_EAGLE-LTSPICE_R0402
R_RESET: 10K; ESP32_WROVER_EAGLE-LTSPICE_R0402
SENSOR2: ESP32_WROVER_BME680_BME680; ESP32_WROVER_BME680_PSON80P300X300X100-8N
SJ1: SJ
TP1, TP2, TP3, TP4, TP5, TP6, TP7, TP8, TP9, TP10, TP11, TP12, TP13, TP14, TP15, TP16, TP17: TPTP20R; TP20R
U1: W25Q512JVEIQ; SON127P600X800X80-9N
U2: ESP32-C6-WROOM-1-N8; XCVR_ESP32-C6-WROOM-1-N8
U3: DS3231SN#; SOIC127P1032X265-16N
U4: MAX17048G+T10; SON50P200X200X80-9N

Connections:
3V3: C1_BAT2.1, C3.+, C9.1, D7.2 (ANODE), IC1.2 (VDD), IC4.5 (VOUT), J3.2, J4.P4 (VDD), Q2.3 (D), R1.1, R1_PINH1.2, R2-PINH1.2, R5.2, R6.2, R7.2, R8.2, R9.2, R10.2, R_BOOT.1, R_CHANGE.1, R_CL1.1, R_RESET.1, TP16.TP, U1.3 (!WP!(IO2)), U1.7 (!HOLD!/!RESET!(IO3)), U1.8 (VCC), U2.2 (3V3), U3.2 (VCC)
32KHZ: R2-PINH1.1, U2.9 (IO1), U3.1 (32KHZ)
DN: D1.4 (I/O2_2), J2.A7, J2.B7
DP: D1.6 (I/O1_2), J2.A6, J2.B6
EPD_3V3: C7.1, EPD_C5.1, J1.15, J1.16, L1.2, Q2.2 (S), TP17.TP
EPD_3V3_C: Q2.1 (G), R_CL1.2, TP13.TP, U2.18 (IO20)
EPD_BUSY: J1.9, TP9.TP, U2.26 (IO3)
EPD_CS: D6.1, J1.12, R9.1, TP10.TP, U2.11 (IO10)
EPD_DC: J1.11, TP11.TP, U2.5 (IO5)
EPD_RST: J1.10, TP12.TP, U2.21 (IO23)
FLASH_CS: D9.1, R5.1, U1.1 (!CS), U2.12 (IO11)
GDR: J1.2, Q3.1 (G), R4.1
GND: BOOT_BUTTON.1, BOOT_BUTTON.2, C1.2, C1_BAT.2, C1_BAT1.2, C1_BAT2.2, C2.2, C2_BAT.2, C3.-, C4_USB.2, C5.2, C5_USB.2, C6.2, C7.2, C8.2, C9.2, C10.2, C10_SUPERCAP.1, CHANGE_BUTTON.1, CHANGE_BUTTON.2, C_DELAY.2, D1.2 (GND), D3.1 (K), D6.2, D8.2, D9.2, D10.2, D11.2, D12.2, EPD_C1.2, EPD_C2.2, EPD_C5.2, EPD_C6.2, EPD_C7.2, EPD_C8.2, EPD_C9.2, EPD_C10.2, EPD_C11.2, EPD_C12.2, IC1.3 (GND), IC4.2 (VSS), J1.8, J1.17, J1.MP1, J1.MP2, J2.A1, J2.A12, J2.B1, J2.B12, J2.MP1, J2.MP2, J2.MP3, J2.MP4, J3.1, J4.G1 (GND_1), J4.G2 (GND_2), J4.G3 (GND_3), J4.G4 (GND_4), J4.P6 (VSS), MCP73831.2 (VSS), R1_PWRUSB.1, R2.1, R2-USB.2, R2-USB1.2, R2_BAT.1, R4.2, RESET_BUTTON.1, RESET_BUTTON.2, SENSOR2.1 (GND), SENSOR2.5 (SDO), SENSOR2.7 (GND), SJ1.1, TP4.TP, TP5.TP, U1.4 (GND), U1.9 (EXP), U2.1 (GND), U2.28 (GND), U2.29_1 (GND), U2.29_2 (GND), U2.29_3 (GND), U2.29_4 (GND), U2.29_5 (GND), U2.29_6 (GND), U2.29_7 (GND), U2.29_8 (GND), U2.29_9 (GND), U3.13 (GND), U4.1 (CTG), U4.4 (GND), U4.6 (QSTRT), U4.9 (EP)
GPIO8: R1.2, U2.10 (IO8)
I2C_PW: C1.1, C2.1, R1_PINH.2, R2-PINH.2, SENSOR2.2 (CSB), SENSOR2.6 (VDDIO), SENSOR2.8 (VDD), U2.17 (IO19)
INT_RTC: R1_PINH1.1, TP15.TP, U2.8 (IO0), U3.3 (SQW/!INT)
IO/BOOT: BOOT_BUTTON.3, BOOT_BUTTON.4, C6.1, R_BOOT.2, U2.15 (IO9)
IO/CHANGE: C10.1, CHANGE_BUTTON.3, CHANGE_BUTTON.4, R_CHANGE.2, U2.23 (IO15)
MISO: D12.1, J4.P7 (DAT0), R8.1, TP6.TP, U1.2 (DO(IO1)), U2.27 (IO2)
MOSI: D11.1, J1.14, J4.P3 (CMD), R7.1, TP7.TP, U1.5 (DI(IO0)), U2.7 (IO7)
unnamed: J2.B5, R2-USB.1
unnamed: C1_BAT1.1, D2.1 (CATHODE), IC4.1 (VIN), IC4.3 (CE), Q1.2 (S)
unnamed: MCP73831.1 (STAT), R1_BAT.1
unnamed: CHG_LED.C, R1_BAT.2
unnamed: J2.A5, R2-USB1.1
unnamed: MCP73831.5 (PROG), R2_BAT.2
unnamed: C4.1, D3.2 (A), D4.1 (K)
unnamed: C_DELAY.1, IC1.5 (CT)
unnamed: EPD_C2.1, J1.5
unnamed: EPD_C1.1, J1.4
unnamed: D7.1 (CATHODE), R_CAPACITOR.2
unnamed: EPD_C12.1, J1.24
unnamed: EPD_C10.1, J1.22
unnamed: EPD_C8.1, J1.20
unnamed: EPD_C7.1, J1.19
unnamed: EPD_C6.1, J1.18
PREVGH: D5.1 (K), EPD_C9.1, J1.21
PREVGL: D4.2 (A), EPD_C11.1, J1.23
RESE: J1.3, Q3.2 (S), R3.1
RESE': R2.2, R3.2, SJ1.2
RESET: C5.1, IC1.1 (VOUT), RESET_BUTTON.3, RESET_BUTTON.4, R_RESET.2, U2.3 (EN)
RTC_RST: U2.16 (IO18), U3.4 (!RST)
RX: TP2.TP, U2.24 (RXD0/GPIO17)
SCK: D10.1, J1.13, J4.P5 (CLK), R6.1, TP8.TP, U1.6 (CLK), U2.6 (IO6)
SCL: J3.4, R2-PINH.1, SENSOR2.4 (SCK), U2.20 (IO22), U3.16 (SCL), U4.7 (SCL)
SDA: J3.3, R1_PINH.1, SENSOR2.3 (SDI), U2.19 (IO21), U3.15 (SDA), U4.8 (SDA)
SRC: C4.2, D5.2 (A), L1.1, Q3.3 (D)
SS_SD: D8.1, J4.P2 (CD/DAT3), R10.1, U2.4 (IO4)
TX: TP1.TP, U2.25 (TXD0/GPIO16)
USB_D+: D1.1 (I/O1_1), U2.14 (IO13)
USB_D-: D1.3 (I/O2_1), U2.13 (IO12)
VBAT: C2_BAT.1, MCP73831.3 (VBAT), Q1.3 (D), TP3.TP, U4.2 (CELL), U4.3 (VDD)
VBUS: C1_BAT.1, C4_USB.1, C5_USB.1, CHG_LED.A, D1.5 (VBUS), D2.2 (ANODE), MCP73831.4 (VIN), PFMF.050.1.2, Q1.1 (G), R1_PWRUSB.2, TP14.TP
VRTC: C8.1, C10_SUPERCAP.2, R_CAPACITOR.1, U3.14 (VBAT)
VUSB: J2.A4, J2.A9, J2.B4, J2.B9, PFMF.050.1.1

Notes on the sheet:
USB C connector & ESD protection
LDO Voltage Regulator
SD Card
ESP32 C6
Display Type Selector
E-Paper Drive Circuit
Li-Po Battery Charging Controller
E-Paper Display Header
EPD Power
Environmental Sensor BME688
Voltage Supervisor + Reset & Boot / IO Button
Battery Charge Level
RTC Module DS3231SN
Test Pads
Qwiic / Stemma QT
SPI ESD Protection Lines
External NOR Flash 64MB
OpenBook Schematic
Dincă Tudor-Cristian

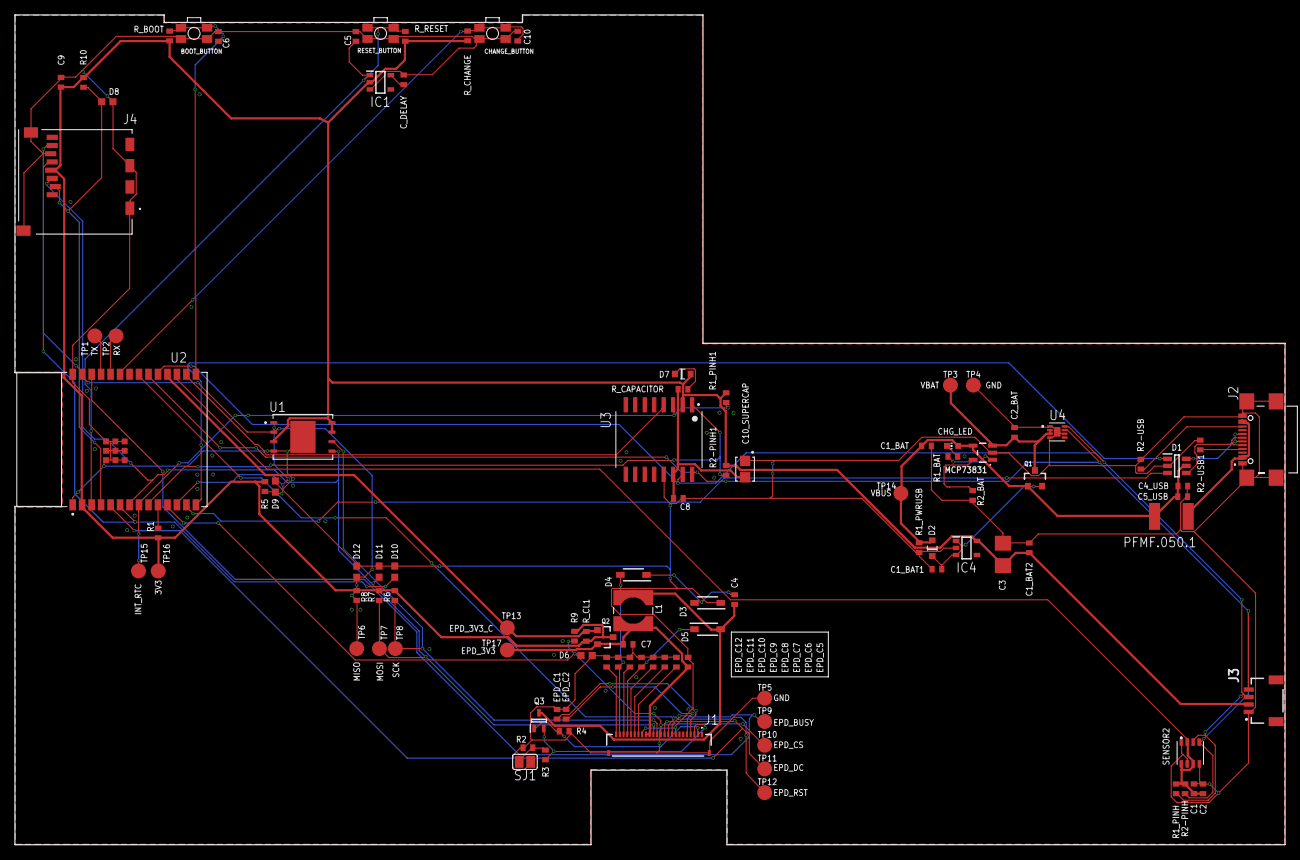
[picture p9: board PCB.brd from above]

Board: 2 copper layers, 170.2 x 111.2 mm, 103 parts (0 on the bottom side), 55 nets.

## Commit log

2025-04-06 Added Hardware files
    [PROIECT_TSC.brd, Proiect_TSC.sch]
2025-04-06 Updated the names of the Hardware files
    [PCB.brd, Schematic.sch]
2025-04-06 Added the Manufacturing files
    [Bill_of_Materials.bom.csv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]
2025-04-13 Project update after the review
    Upon receiving a review, i updated my project to fix the signaled issues:
    - 90 degrees wires were eliminated
    - measurements around the board were added
    - the silkscreen has been cleared and enhanced to not intersect with the wires or the components
    - the ground plane is not covering the entire surface of both the TOP and BOTTOM layer
    - the board has now the correct 1mm width
    [PCB.brd]

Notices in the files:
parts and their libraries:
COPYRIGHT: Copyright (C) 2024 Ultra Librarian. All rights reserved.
